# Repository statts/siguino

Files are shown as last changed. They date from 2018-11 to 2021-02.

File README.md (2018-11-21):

# Siguino

Siguino final design

Low power board based on Arduino Pro Mini with in-built Sigfox network support

Siguino Eagle schematics, libraries and Arduino code created by Scott Tattersall

Further project info and manufactured boards for purchase at https://siguino.com

Detailed Getting Started Guide: https://siguino.com/step-by-step-guide/

3rd Party libraries / resources used:

Hardware:
- Many basic components (resistors, capacitors, etc) are from the SparkFun Eagle libraries
- LIS3DH accelerometer from SparkFun: https://github.com/sparkfun/SparkFun_LIS3DH_Arduino_Library
- Wisol Chip from hellogitty/WiSol (greatech.de) https://github.com/hellogitty/WiSOL

Software:
 (To install, go to url and "download zip", in Arduino IDE click Sketch->Include Library->Add zip and select downloaded zip file)
- LowPower library from RocketScream: https://github.com/rocketscream/Low-Power
- SparkFun LIS3DH library (https://github.com/sparkfun/SparkFun_LIS3DH_Arduino_Library)
- Arduino Sensors library (https://github.com/adafruit/Adafruit_Sensor)
- Arduino Bosch BME280 library (https://github.com/adafruit/Adafruit_BME280_Library)
- AltSoftSerial (https://github.com/PaulStoffregen/AltSoftSerial)

Enclosure:
- CAD (STL) files for sample enclosure that can be 3d printed as needed
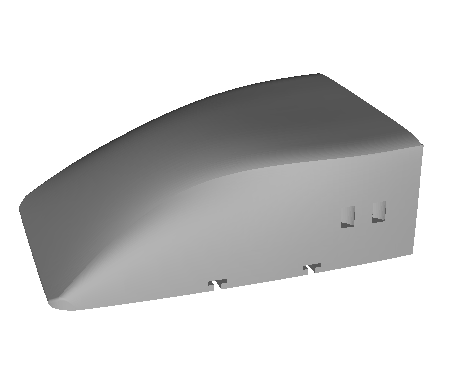
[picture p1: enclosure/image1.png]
Siguino enclosure side view

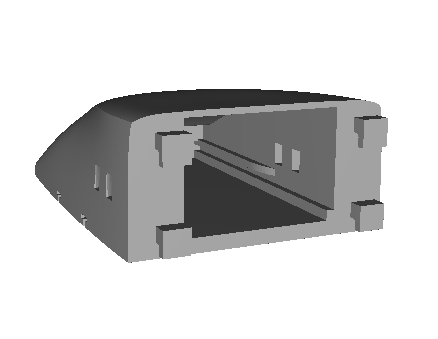
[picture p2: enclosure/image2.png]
Siguino enclosure inside


# Sample projects
Along with the sigfox_sensors project that sends all sensor information here is another simple example project:

- Weather Station (arduino/weather_station)
Follow the same above software section to install the approriate libraries first, then download the weather station code.
The code can be flashed onto the Siguino via a standard FTDI breakout board (3.3v version only!), e.g. 
https://www.sparkfun.com/products/9873

The code: A simple weather station that sends avg temperature, light level, humidity and atmospheric pressure. If using Wia to process the data (see above getting started link), these can be easily graphed in Wia using a Wia Widget:
https://developers.wia.io/docs/add-a-widget

More information on integrating with Wia:
https://siguino.com/getting-started-with-siguino-and-wia-io/

Example:

Sample Temperature Chart (Wia)

# Eagle libraries
In eagle, set the directories for libraries to add the libary files included here if not already included, e.g.
$EAGLEDIR/lbr:{PROJECT-DIR}/Libraries/SparkFun-Eagle-Libraries-master:{PROJECT-DIR}/Libraries/WiSOL-master/Eagle_Library

Plus use the New Library -> execute script to add the components in script form from the scripts dir

# Hardware Revision History:

Rev 0.1: First version, trimmed board

Rev 0.2:
1) Add Reset Pin out as well as dtr for bootloading
2) Change C8 10uf format to standard 0603
3) Update routing to account for unsaved work
4) Re-write/tidy arduino sketch
5) Add de-coupling caps 10uf, 100nf to Accel chip VDD
6) Connect INT1 pin on Accel to D3

Rev 0.3:
1) Add Battery Holder
2) Add Reverse polarity Protection
3) Reposition Antenna

Rev 0.4:
1) Replace Temperature chip
2) Re-route temperature chip
3) Add registration hole for battery holder
4) Minor re-routing of vias under chips

Rev 0.5 / 1.0:
1) Added Magnetometer
2) Replaced temp chip with Temp & Pressure (Bosch BME 280)
3) Re-routing for manufacturing

Rev 1.1:
1) Improved Schematic (with thanks to Marnix Janse)
2) Improved Antenna trace (with thanks to Marnix Janse)

# Licence & Contact

Siguino Hardware and Software licenced under GPLv3, any questions or issues please contact scott@dock.ie

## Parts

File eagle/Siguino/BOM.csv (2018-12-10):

Part | Value | Device | Package | Description | DESCRIPTION | DIGI-KEY_PART_NUMBER | DIGI-KEY_PURCHASE_URL | MF | MP | PACKAGE | PROD_ID | SF_ID | VALUE
ANT1 | PROOB471 | PROANT_PRO-OB-471_ONBOARD | PROANT_ONBOARD_SMD_868_915 | Proant OnBoard Antenna PRO-OB-471 for 868/915MHz comms (e.g. SigFox)
BATT1 | SPARKFUN-BATTERIES_CR2-BATTERY-HOLDERPTH | SPARKFUN-BATTERIES_CR2-BATTERY-HOLDERPTH | SPARKFUN-BATTERIES_BATTERYHOLDER-CR2 | CR2 Battery holder from MPD, see DigiKey product here:
C1 | 0.1uF | 0.1UF-0603-25V-5% | 0603 | 0.1µF ceramic capacitors |  |  |  |  |  |  | CAP-08604 |  | 0.1uF
C2 | 0.1uF | 0.1UF-0603-25V-5% | 0603 | 0.1µF ceramic capacitors |  |  |  |  |  |  | CAP-08604 |  | 0.1uF
C3 | 0.1uF | 0.1UF-0603-25V-5% | 0603 | 0.1µF ceramic capacitors |  |  |  |  |  |  | CAP-08604 |  | 0.1uF
C4 | 0.6pF | 0.8PF-0402-50V-0.1PF | 0402 | 0.8pF ceramic capacitors |  |  |  |  |  |  | CAP-13456 |  | 0.8pF
C5 | 2.2pF | 0.8PF-0402-50V-0.1PF | 0402 | 0.8pF ceramic capacitors |  |  |  |  |  |  | CAP-13456 |  | 0.8pF
C6 | 0.7pF | 0.8PF-0402-50V-0.1PF | 0402 | 0.8pF ceramic capacitors |  |  |  |  |  |  | CAP-13456 |  | 0.8pF
C7 | 0 OHM | RESISTOR0402 | 0402 | Generic Resistor Package
C8 | 100nF | 0.1UF-0603-25V-5% | 0603 | 0.1µF ceramic capacitors |  |  |  |  |  |  | CAP-08604 |  | 0.1uF
C9 | 10nF | 10NF-0603-50V-10% | 0603 | 0.01uF/10nF/10,000pF ceramic capacitors |  |  |  |  |  |  | CAP-00867 |  | 10nF
C10 | 0.1uF | 0.1UF-0603-25V-(+80/-20%) | 0603 | 0.1µF ceramic capacitors |  |  |  |  |  |  | CAP-00810 |  | 0.1uF
C11 | 0.1uF | 0.1UF-0603-25V-5% | 0603 | 0.1µF ceramic capacitors |  |  |  |  |  |  | CAP-08604 |  | 0.1uF
C12 | 100pF | 100PF-0603-50V-5% | 0603 | 100pF/0.1nF ceramic capacitors |  |  |  |  |  |  | CAP-07883 |  | 100pF
C13 | 0.1uF | 0.1UF-0603-25V-(+80/-20%) | 0603 | 0.1µF ceramic capacitors |  |  |  |  |  |  | CAP-00810 |  | 0.1uF
C15 | 10uF | 10UF-0603-6.3V-20% | 0603 | 10.0µF ceramic capacitors |  |  |  |  |  |  | CAP-11015 |  | 10uF
D1 | RED | LED-RED0603 | LED-0603 | Red SMD LED |  |  |  |  |  |  | DIO-00819 |  | RED
HALL1 | TR-J_AH9246-W7 | TR-J_AH9246-W7 | TR-J_SC-59 | Hall effect switch, surface mount, part number AH9246-W-7
J1 | FTDI Basic | 6_PIN_SERIAL_TARGET | 1X06 | 6-pin header connection for use with the FTDI BASIC" pinout - TARGET SIDE."
J2 |  | CONN_12 | 1X12 | Multi connection point. Often used as Generic Header-pin footprint for 0.1 inch spaced/style header connections
J3 |  | CONN_03 | 1X03 | Multi connection point. Often used as Generic Header-pin footprint for 0.1 inch spaced/style header connections
Q1 | MOSFET P-CH 20V 5.3A SOT-23 | MOSFET_PCHSI2323DDS | SOT23-3 | P-channel MOSFETs |  |  |  |  |  |  | SI2323DDS-T1-GE3 |  | MOSFET P-CH 20V 5.3A SOT-23
R1 | 330 | 330OHM-0603-1/10W-1% | 0603 | 330Ω resistor |  |  |  |  |  |  | RES-00818 |  | 330
R2 | PHOTOCELLPTH | PHOTOCELLPTH | PHOTOCELL | Photocell (Photodetector, Photo Resistor, CdS) |  |  |  |  |  |  | COMP-09129 | SEN-09088
R3 | 1k | 1KOHM-0603-1/10W-1% | 0603 | 1kΩ resistor |  |  |  |  |  |  | RES-07856 |  | 1k
R4 | 10k | 10KOHM-0603-1/10W-1% | 0603 | 10kΩ resistor |  |  |  |  |  |  | RES-00824 |  | 10k
R5 | 100k | 100KOHM-0603-1/10W-1% | 0603 | 100kΩ resistor |  |  |  |  |  |  | RES-07828 |  | 100k
R6 | 10k | 10KOHM-0603-1/10W-1% | 0603 | 10kΩ resistor |  |  |  |  |  |  | RES-00824 |  | 10k
R7 | 10k | 10KOHM-0603-1/10W-1% | 0603 | 10kΩ resistor |  |  |  |  |  |  | RES-00824 |  | 10k
SFM1 |  | WISOL_WSSFM10HANDSOLDER | WISOL_WSSFM10 | WiSOL WSSFM10 Sigfox Module with PCB Footprint to enable handsolder
U1 | ATMEGA328P_TQFP | ATMEGA328P_TQFP | TQFP32-08 | Popular 328P in QFP |  |  |  |  |  |  | IC-09069 |  | ATMEGA328P_TQFP
U2 | LIS3MDLTR_LIS3MDLTR | LIS3MDLTR_LIS3MDLTR | LIS3MDLTR_LGA12R50P4X4_200X200X100 | LIS3MDL Series 3 Axis ±2/±8/±12/±16 g 3.6V High Performance Magnetometer LGA-12 | SENSOR MAGMTR I2C/SPI 12LGA | 497-13892-1-ND | https://www.digikey.co.uk/product-detail/en/stmicroelectronics/LIS3MDLTR/497-13892-1-ND/4309737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 | STMicroelectronics | LIS3MDLTR | VFLGA-12 STMicroelectronics
U3 | SPARKFUN-SENSORS_LIS3DH | SPARKFUN-SENSORS_LIS3DH | SPARKFUN-SENSORS_LGA-16-3X3 | ST Microelectronics LIS3DH 3-Axis +/-2/4/8/16g SPI/I2C Accelerometer |  |  |  |  |  |  | IC-13419 | N/A
U4 | BME280 | BME280COMPONENTLIBRARY_BME280 | BME280COMPONENTLIBRARY_BME280_LGA |  |  |  |  |  |  |  | IC-13090 |  | BME280
Y1 | 8MHz | RESONATOR-8MHZSMD_3.2X1.3 | RESONATOR-SMD-3.2X1.3 | 8MHz Resonator |  |  |  |  |  |  | XTAL-08895 |  | 8MHz

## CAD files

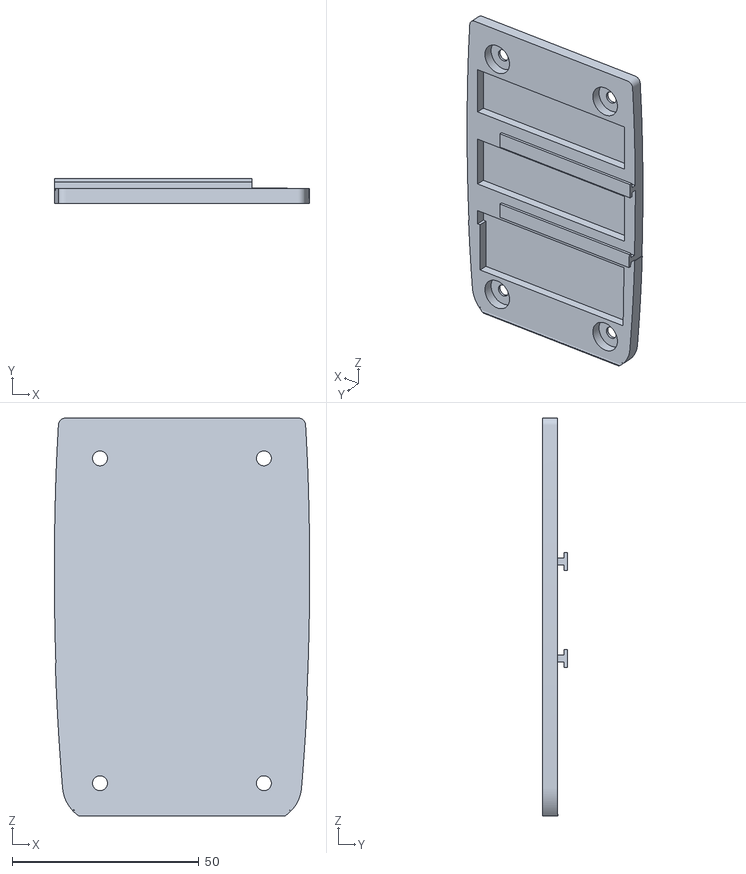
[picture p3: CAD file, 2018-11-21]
enclosure/MOUNTING PLATE.STL
68.5 x 6.71 x 106.7

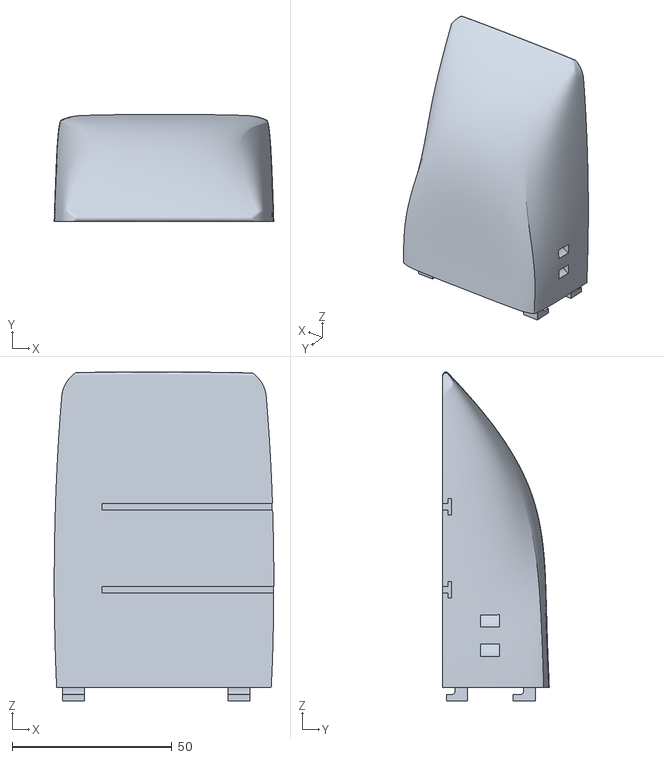
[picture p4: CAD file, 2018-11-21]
enclosure/ENCLOSURE.STL
68.8 x 33.4 x 103.0

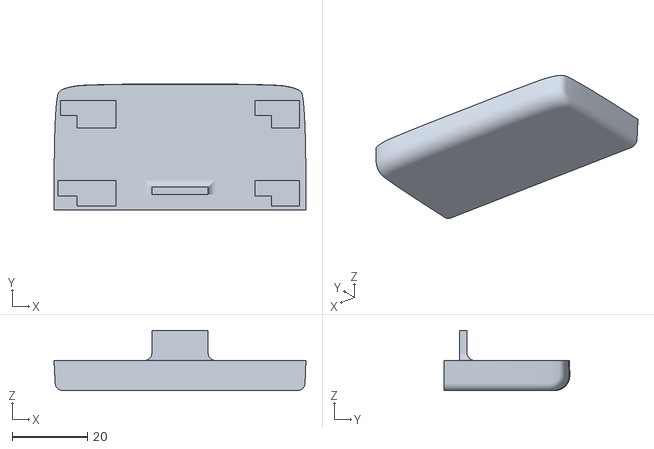
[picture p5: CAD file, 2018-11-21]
enclosure/BATTERY CAP.STL
67.2 x 33.5 x 16.0

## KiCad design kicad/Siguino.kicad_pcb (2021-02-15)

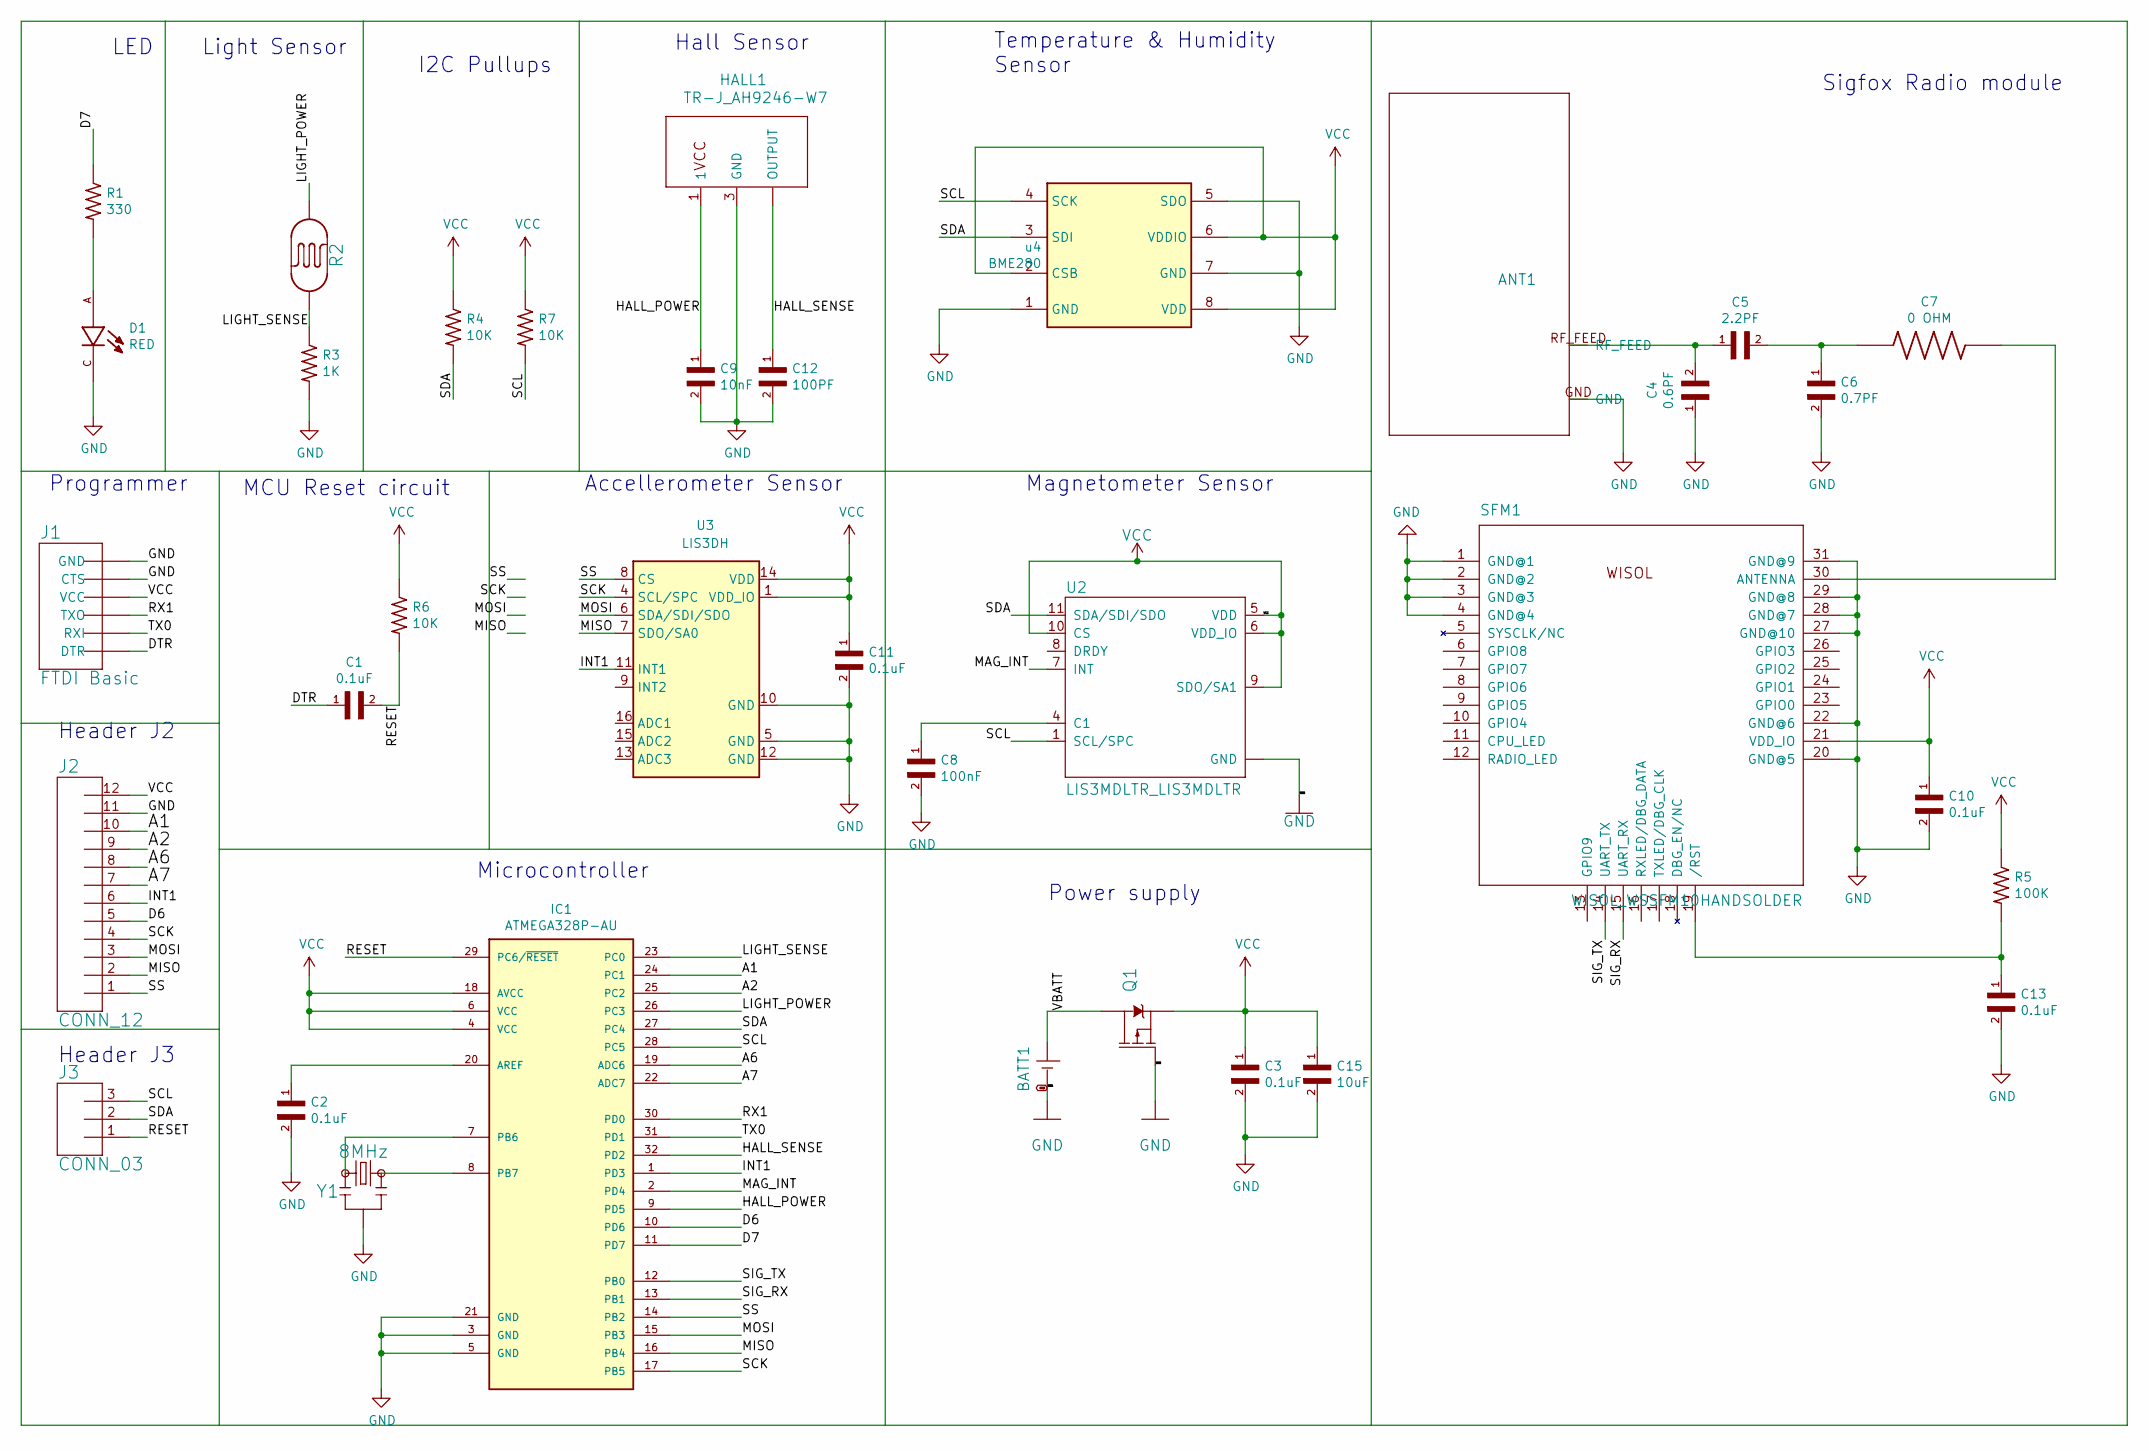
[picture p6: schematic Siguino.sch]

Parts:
ANT1: PROOB471; ONBOARD_SMD_2400
BATT1: SPARKFUN-BATTERIES_CR2-BATTERY-HOLDERPTH; SPARKFUN-BATTERIES_BATTERYHOLDER-CR2
C1, C2, C3, C10, C11, C13: 0.1uF; CAPC0603X33N
C4: 0.6PF; CAPC0402X22N
C5: 2.2PF; CAPC0402X22N
C6: 0.7PF; CAPC0402X22N
C7: 0 OHM; RESC1005X35N
C8: 100nF; CAPC0603X33N
C9: 10nF; CAPC0603X33N
C12: 100PF; CAPC0603X33N
C15: 10uF; CAPC0603X33N
D1: RED; LED_SML-D12Y1WT86
HALL1: TR-J_AH9246-W7; SC-59
IC1: ATMEGA328P-AU; QFP80P900X900X120-32N
J1: FTDI Basic; 1X06
J2: CONN_12; 1X12
J3: CONN_03; 1X03
Q1: MOSFET P-CH 20V 5.3A SOT-23; SOT23-3
R1: 330; RESC1608X50N; Tolerance .1%; Voltage_Rating 50 V
R2: PHOTOCELLPTH; PHOTOCELL
R3: 1K; RESC1608X50N; Tolerance .1%; Voltage_Rating 50 V
R4, R6, R7: 10K; RESC1608X50N; Tolerance .1%; Voltage_Rating 50 V
R5: 100K; RESC1608X50N; Tolerance .1%; Voltage_Rating 50 V
SFM1: WISOL_WSSFM10HANDSOLDER; WISOL_WSSFM10
U2: LIS3MDLTR_LIS3MDLTR; LIS3MDLTR_LGA12R50P4X4_200X200X100
U3: LIS3DH; LGA-16_3x3mm_P0.5mm_LayoutBorder3x5y
Y1: 8MHz; RESONATOR-SMD-3.2X1.3
u4: BME280; Bosch_LGA-8_2.5x2.5mm_P0.65mm_ClockwisePinNumbering

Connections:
/A1: IC1.24 (PC1), J2.10
/A2: IC1.25 (PC2), J2.9
/A6: IC1.19 (ADC6), J2.8
/A7: IC1.22 (ADC7), J2.7
/D6: IC1.10 (PD6), J2.5
/D7: IC1.11 (PD7), R1.1
/DTR: C1.1, J1.1 (DTR)
/HALL_POWER: C9.1, HALL1.1, IC1.9 (PD5)
/HALL_SENSE: C12.1, HALL1.2 (OUTPUT), IC1.32 (PD2)
/INT1: IC1.1 (PD3), J2.6, U3.11 (INT1)
/LIGHT_POWER: IC1.26 (PC3), R2.1
/LIGHT_SENSE: IC1.23 (PC0), R2.2, R3.1
/MAG_INT: IC1.2 (PD4), U2.7 (INT)
/MISO: IC1.16 (PB4), J2.2, U3.7 (SDO/SA0)
/MOSI: IC1.15 (PB3), J2.3, U3.6 (SDA/SDI/SDO)
/RESET: C1.2, IC1.29 (PC6/~RESET), J3.1, R6.2
/RX1: IC1.30 (PD0), J1.3 (TXO)
/SCK: IC1.17 (PB5), J2.4, U3.4 (SCL/SPC)
/SCL: IC1.28 (PC5), J3.3, R7.2, U2.1 (SCL/SPC), u4.4 (SCK)
/SDA: IC1.27 (PC4), J3.2, R4.2, U2.11 (SDA/SDI/SDO), u4.3 (SDI)
/SIG_RX: IC1.13 (PB1), SFM1.15 (UART_RX)
/SIG_TX: IC1.12 (PB0), SFM1.14 (UART_TX)
/SS: IC1.14 (PB2), J2.1, U3.8 (CS)
/TX0: IC1.31 (PD1), J1.2 (RXI)
/VBATT: BATT1.VBATT, Q1.3 (D)
GND: ANT1.GND, BATT1.GND, C2.2, C3.2, C4.1, C6.2, C8.2, C9.2, C10.2, C11.2, C12.2, C13.2, C15.2, D1.C, HALL1.3 (GND), IC1.3 (GND), IC1.5 (GND), IC1.21 (GND), J1.5 (CTS), J1.6 (GND), J2.11, Q1.1 (G), R3.2, SFM1.1 (GND@1), SFM1.2 (GND@2), SFM1.3 (GND@3), SFM1.4 (GND@4), SFM1.20 (GND@5), SFM1.22 (GND@6), SFM1.27 (GND@10), SFM1.28 (GND@7), SFM1.29 (GND@8), SFM1.31 (GND@9), U2.2 (GND), U2.3 (GND), U2.12 (GND), U3.5 (GND), U3.10 (GND), U3.12 (GND), Y1.2, u4.1 (GND), u4.5 (SDO), u4.7 (GND)
unnamed: ANT1.RF_FEED, C4.2, C5.1
unnamed: C2.1, IC1.20 (AREF)
unnamed: C5.2, C6.1, C7.1
unnamed: C7.2, SFM1.30 (ANTENNA)
unnamed: C8.1, U2.4 (C1)
unnamed: C13.1, R5.2, SFM1.19 (/RST)
unnamed: D1.A, R1.2
unnamed: IC1.7 (PB6), Y1.1
unnamed: IC1.8 (PB7), Y1.3
VCC: C3.1, C10.1, C11.1, C15.1, IC1.4 (VCC), IC1.6 (VCC), IC1.18 (AVCC), J1.4 (VCC), J2.12, Q1.2 (S), R4.1, R5.1, R6.1, R7.1, SFM1.21 (VDD_IO), U2.5 (VDD), U2.6 (VDD_IO), U2.9 (SDO/SA1), U2.10 (CS), U3.1 (VDD_IO), U3.14 (VDD), u4.2 (CSB), u4.6 (VDDIO), u4.8 (VDD)

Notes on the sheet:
Light Sensor
I2C Pullups
Hall Sensor
Temperature & Humidity Sensor
Magnetometer Sensor
Accellerometer Sensor
LED
MCU Reset circuit
Programmer
Header J2
Header J3
Microcontroller
Power supply
Sigfox Radio module

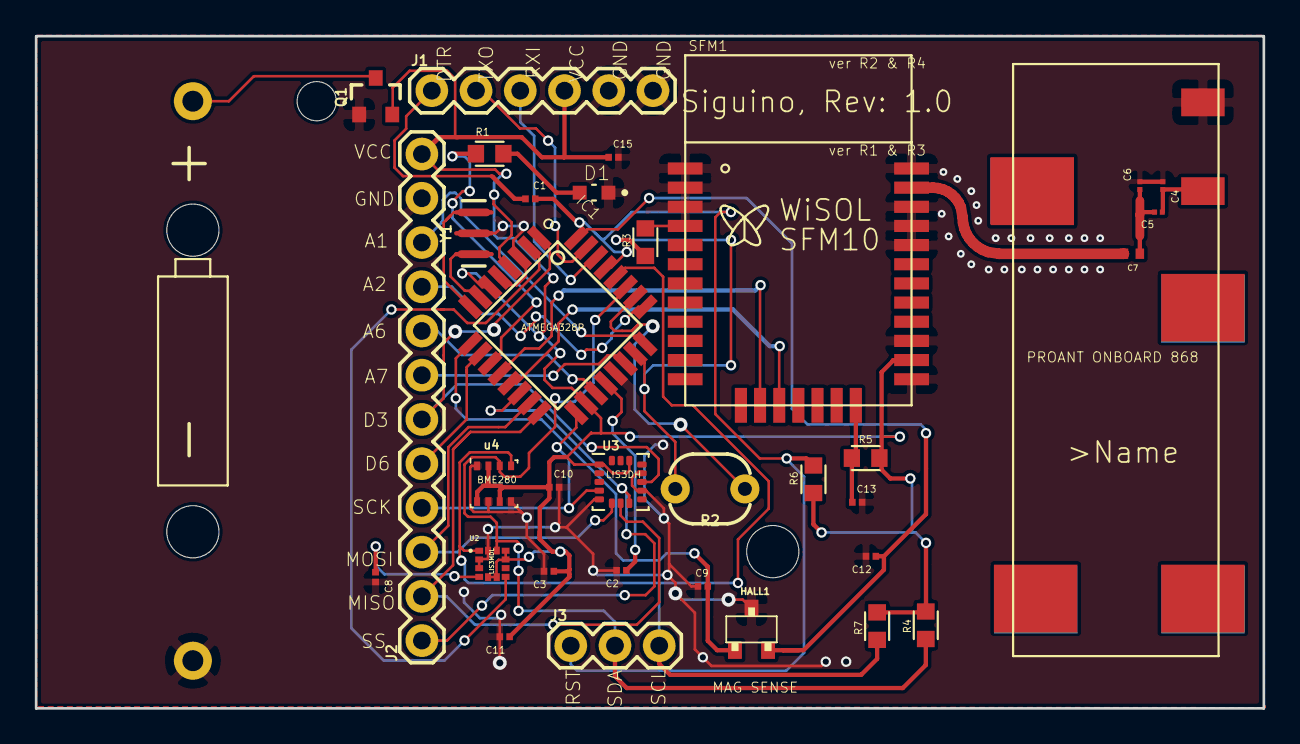
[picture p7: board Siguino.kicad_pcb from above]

Board: 16 copper layers, 70.5 x 38.6 mm, 36 parts (0 on the bottom side), 36 nets.

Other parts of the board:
@HOLE0: (no value)

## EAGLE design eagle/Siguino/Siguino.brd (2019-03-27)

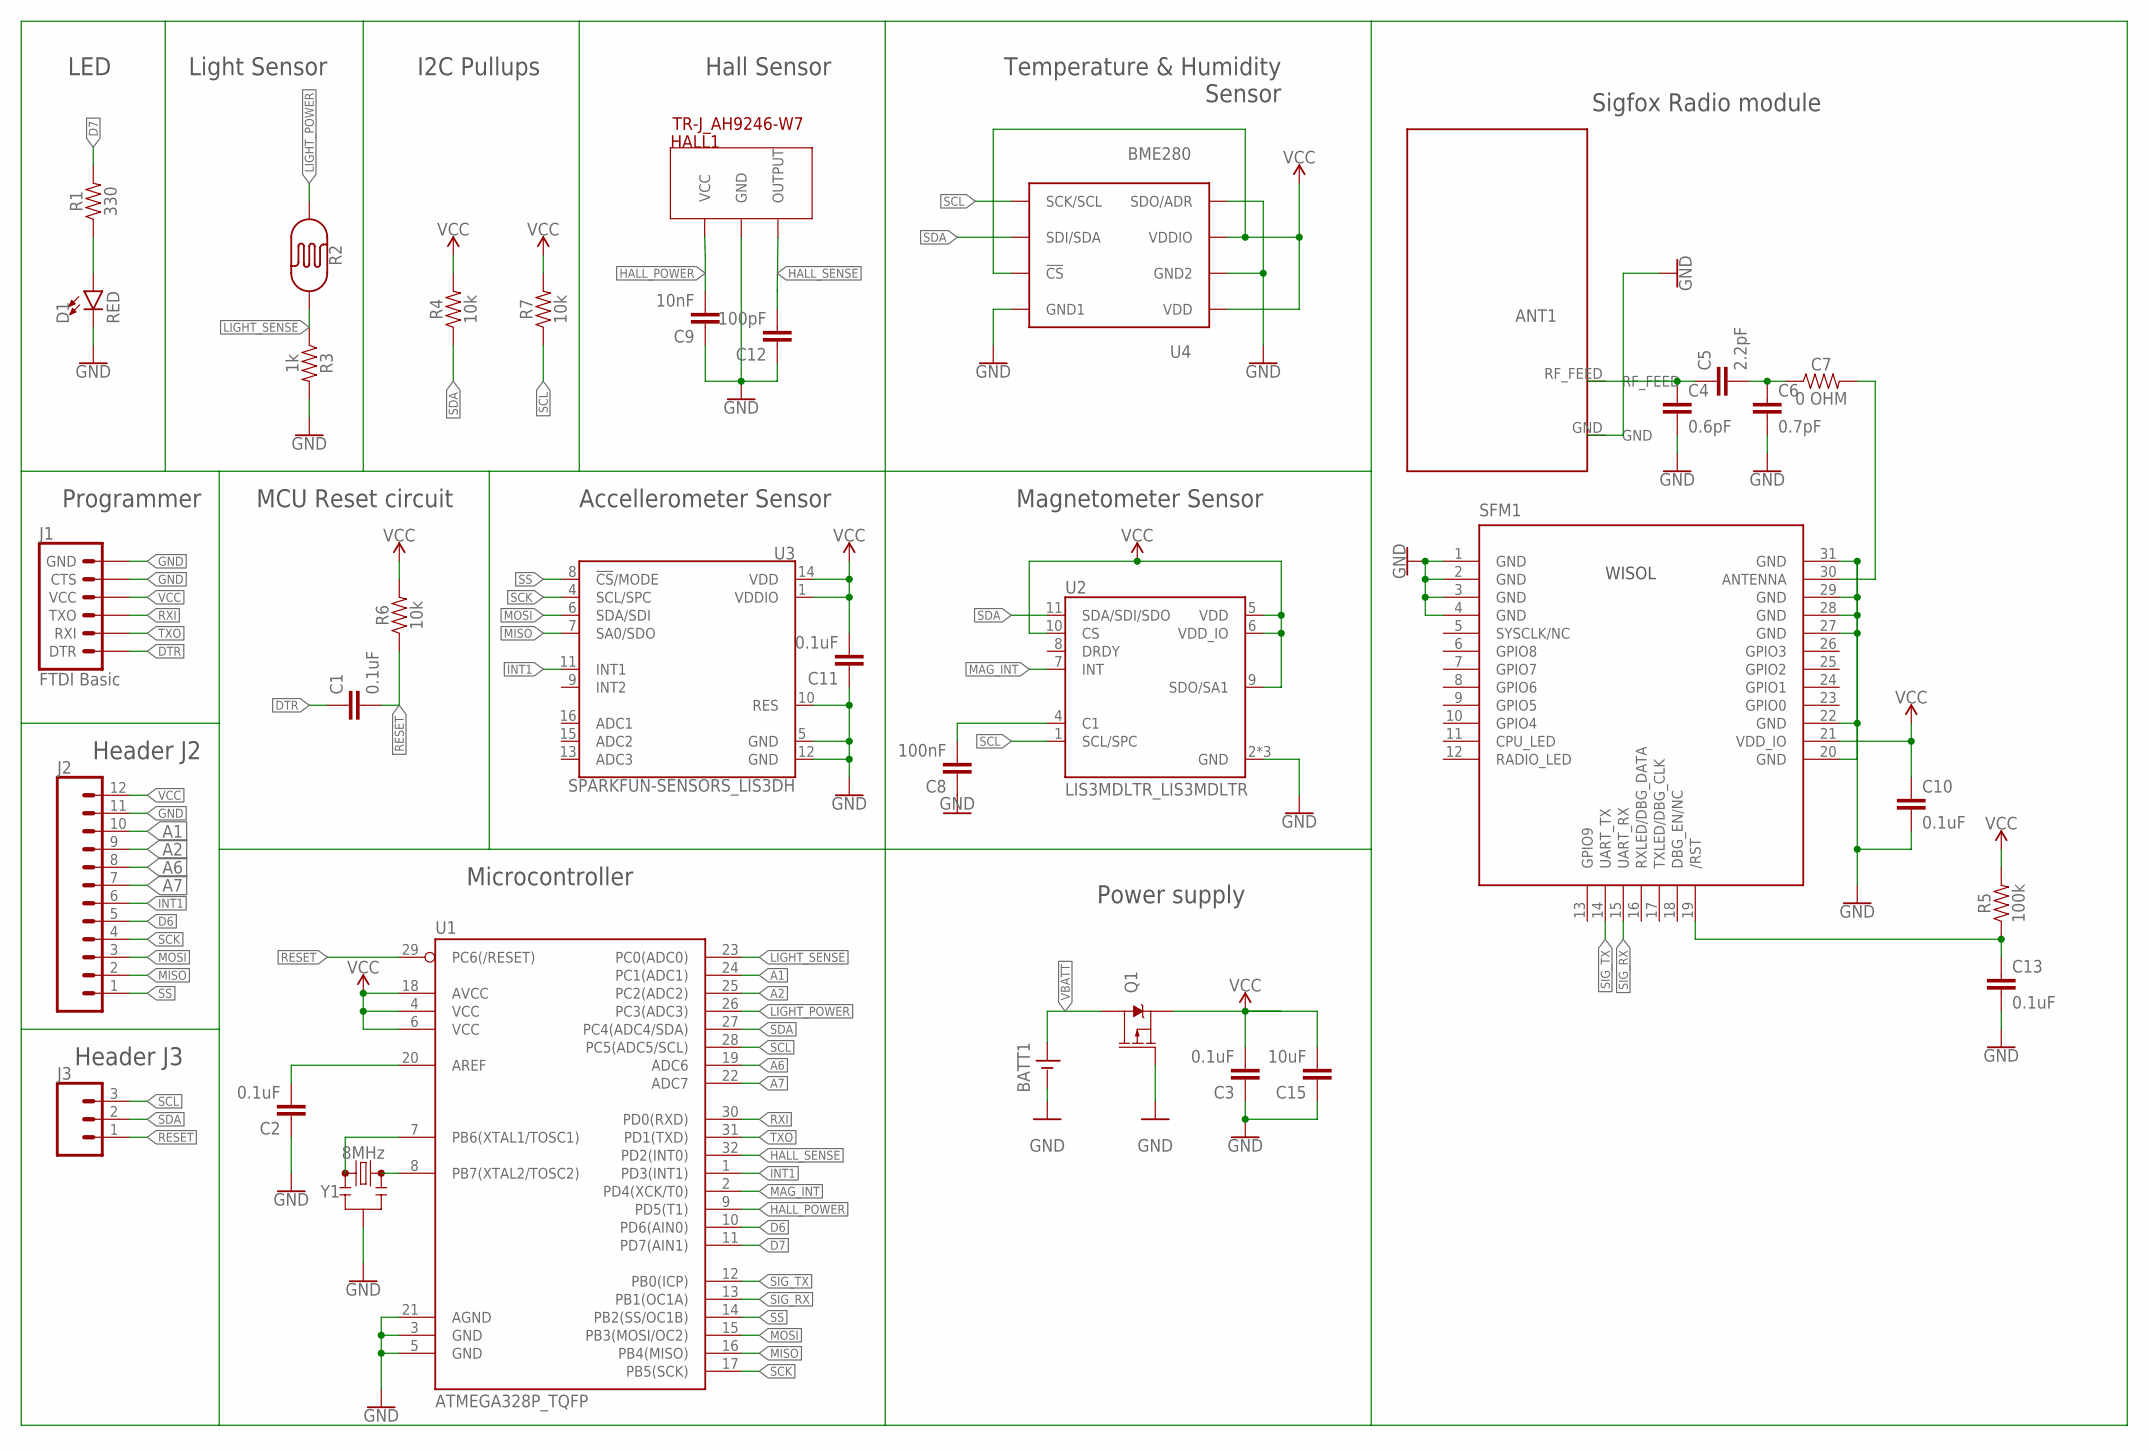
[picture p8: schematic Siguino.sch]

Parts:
ANT1: PROOB471; ONBOARD_SMD_2400
BATT1: SPARKFUN-BATTERIES_CR2-BATTERY-HOLDERPTH; SPARKFUN-BATTERIES_BATTERYHOLDER-CR2
C1, C2, C3, C10, C11, C13: 0.1uF; 0603
C4: 0.6pF; 0402
C5: 2.2pF; 0402
C6: 0.7pF; 0402
C7: 0 OHM; 0402
C8: 100nF; 0603
C9: 10nF; 0603
C12: 100pF; 0603
C15: 10uF; 0603
D1: RED; LED-0603
HALL1: TR-J_AH9246-W7; TR-J_SC-59
J1: FTDI Basic; 1X06
J2: CONN_12; 1X12
J3: CONN_03; 1X03
Q1: MOSFET P-CH 20V 5.3A SOT-23; SOT23-3
R1: 330; 0603
R2: PHOTOCELLPTH; PHOTOCELL
R3: 1k; 0603
R4, R6, R7: 10k; 0603
R5: 100k; 0603
SFM1: WISOL_WSSFM10HANDSOLDER; WISOL_WSSFM10
U1: ATMEGA328P_TQFP; TQFP32-08
U2: LIS3MDLTR_LIS3MDLTR; LIS3MDLTR_LGA12R50P4X4_200X200X100
U3: SPARKFUN-SENSORS_LIS3DH; SPARKFUN-SENSORS_LGA-16-3X3
U4: BME280; BME280COMPONENTLIBRARY_BME280_LGA
Y1: 8MHz; RESONATOR-SMD-3.2X1.3

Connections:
A1: J2.10, U1.24 (PC1(ADC1))
A2: J2.9, U1.25 (PC2(ADC2))
A6: J2.8, U1.19 (ADC6)
A7: J2.7, U1.22 (ADC7)
D6: J2.5, U1.10 (PD6(AIN0))
D7: R1.2, U1.11 (PD7(AIN1))
DTR: C1.1, J1.1 (DTR)
GND: ANT1.GND, BATT1.GND, C2.1, C3.1, C4.2, C6.2, C8.1, C9.1, C10.2, C11.1, C12.1, C13.2, C15.1, D1.C, HALL1.3 (GND), J1.5 (CTS), J1.6 (GND), J2.11, Q1.1 (G), R3.2, SFM1.1 (GND), SFM1.2 (GND), SFM1.3 (GND), SFM1.4 (GND), SFM1.20 (GND), SFM1.22 (GND), SFM1.27 (GND), SFM1.28 (GND), SFM1.29 (GND), SFM1.31 (GND), U1.3 (GND), U1.5 (GND), U1.21 (AGND), U2.2 (GND), U2.3 (GND), U2.12 (GND), U3.5 (GND), U3.10 (RES), U3.12 (GND), U4.P$1 (GND1), U4.P$5 (SDO/ADR), U4.P$7 (GND2), Y1.2
HALL_POWER: C9.2, HALL1.1 (VCC), U1.9 (PD5(T1))
HALL_SENSE: C12.2, HALL1.2 (OUTPUT), U1.32 (PD2(INT0))
INT1: J2.6, U1.1 (PD3(INT1)), U3.11 (INT1)
LIGHT_POWER: R2.1, U1.26 (PC3(ADC3))
LIGHT_SENSE: R2.2, R3.1, U1.23 (PC0(ADC0))
MAG_INT: U1.2 (PD4(XCK/T0)), U2.7 (INT)
MISO: J2.2, U1.16 (PB4(MISO)), U3.7 (SA0/SDO)
MOSI: J2.3, U1.15 (PB3(MOSI/OC2)), U3.6 (SDA/SDI)
unnamed: C2.2, U1.20 (AREF)
unnamed: U1.8 (PB7(XTAL2/TOSC2)), Y1.3
unnamed: U1.7 (PB6(XTAL1/TOSC1)), Y1.1
unnamed: ANT1.RF_FEED, C4.1, C5.1
unnamed: C13.1, R5.1, SFM1.19 (/RST)
unnamed: C7.2, SFM1.30 (ANTENNA)
unnamed: C5.2, C6.1, C7.1
unnamed: C8.2, U2.4 (C1)
unnamed: D1.A, R1.1
RESET: C1.2, J3.1, R6.1, U1.29 (PC6(/RESET))
RXI: J1.3 (TXO), U1.30 (PD0(RXD))
SCK: J2.4, U1.17 (PB5(SCK)), U3.4 (SCL/SPC)
SCL: J3.3, R7.1, U1.28 (PC5(ADC5/SCL)), U2.1 (SCL/SPC), U4.P$4 (SCK/SCL)
SDA: J3.2, R4.1, U1.27 (PC4(ADC4/SDA)), U2.11 (SDA/SDI/SDO), U4.P$3 (SDI/SDA)
SIG_RX: SFM1.15 (UART_RX), U1.13 (PB1(OC1A))
SIG_TX: SFM1.14 (UART_TX), U1.12 (PB0(ICP))
SS: J2.1, U1.14 (PB2(SS/OC1B)), U3.8 (!CS!/MODE)
TXO: J1.2 (RXI), U1.31 (PD1(TXD))
VBATT: BATT1.VBATT, Q1.3 (D)
VCC: C3.2, C10.1, C11.2, C15.2, J1.4 (VCC), J2.12, Q1.2 (S), R4.2, R5.2, R6.2, R7.2, SFM1.21 (VDD_IO), U1.4 (VCC), U1.6 (VCC), U1.18 (AVCC), U2.5 (VDD), U2.6 (VDD_IO), U2.9 (SDO/SA1), U2.10 (CS), U3.1 (VDDIO), U3.14 (VDD), U4.P$2 (!CS), U4.P$6 (VDDIO), U4.P$8 (VDD)

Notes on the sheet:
Light Sensor
I2C Pullups
Hall Sensor
Temperature & Humidity Sensor
Magnetometer Sensor
Accellerometer Sensor
LED
MCU Reset circuit
Programmer
Header J2
Header J3
Microcontroller
Power supply
Sigfox Radio module

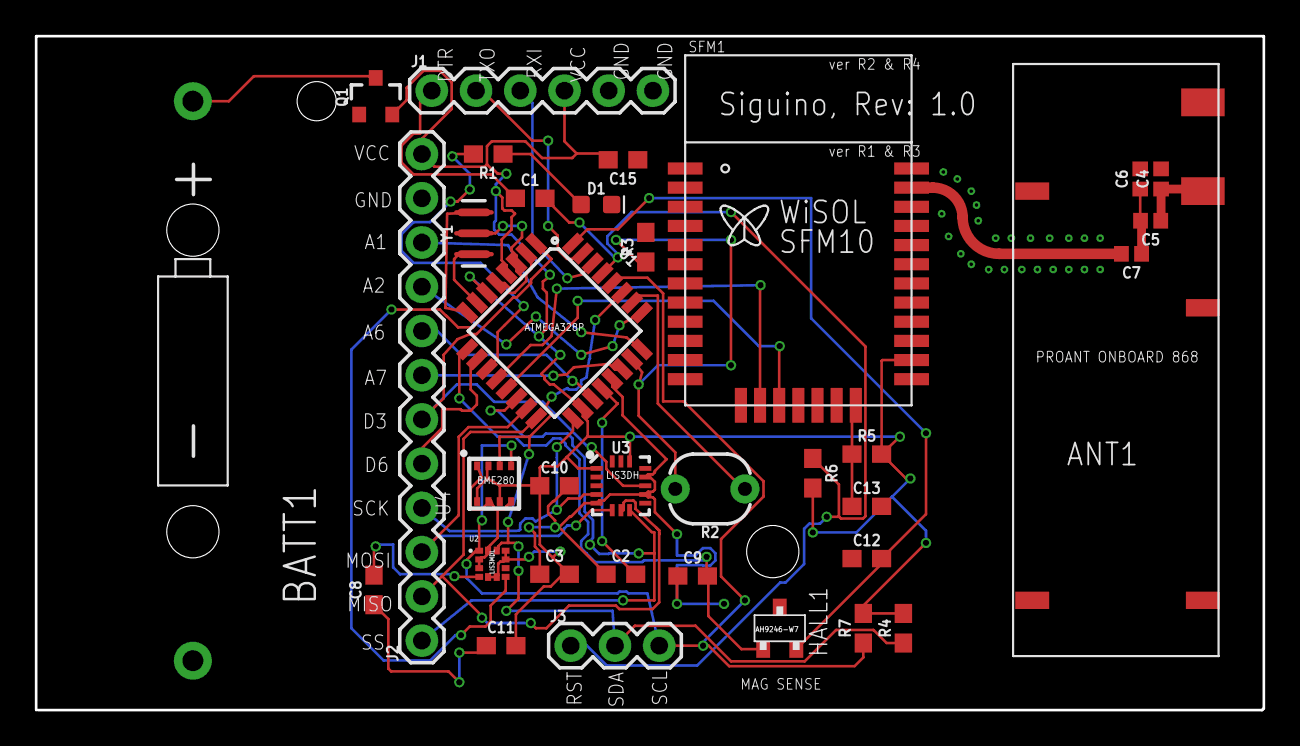
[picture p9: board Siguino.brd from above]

Board: 2 copper layers, 70.5 x 38.7 mm, 35 parts (0 on the bottom side), 36 nets.

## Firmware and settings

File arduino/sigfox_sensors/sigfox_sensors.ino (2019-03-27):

//third-party libraries (install per normal Arduino instructions: https://www.arduino.cc/en/hacking/libraries
#include <LowPower.h> //from RocketScream: https://github.com/rocketscream/Low-Power
#include <SparkFunLIS3DH.h> // from SparkFun: https://github.com/sparkfun/SparkFun_LIS3DH_Arduino_Library
#include <Adafruit_BME280.h>

#include "BitPacker.h"
#include "util.h"
#include "Sigfox.h"
#include "accel.h"
#include "magnet.h"

#define SEALEVELPRESSURE_HPA (1013.25)

Adafruit_BME280 bme; // I2C
//Adafruit_BMP280 bmp(BMP_CS); // hardware SPI
//Adafruit_BMP280 bmp(BMP_CS, BMP_MOSI, BMP_MISO,  BMP_SCK);

const byte BME_ADDRESS   =  0x76;

//set to false for debug and to avoid sending messages but still take sensor readings
bool SEND_SIGFOX_MESSAGES = true;

//declare LIS3DH accelerometer
LIS3DH myIMU(SPI_MODE, 10); // constructed with parameters for SPI and cs pin number

//"global" vars
int period_count = SIGFOX_WAIT_PERIODS; //start at max so initial message is sent on startup
int num_readings = 0;
volatile byte shock_state = LOW;
volatile int count = 0;
volatile bool interrupt_listen_shock = true;
bool shock_powered_down = false;
volatile byte mag_state = HIGH;
volatile bool interrupt_listen_mag = true;
volatile bool state_changed_mag = false;
bool mag_opened = false;
unsigned int seq_num = 0;
enum POWER_MODE {OFF = 0, ON = 1};
int init_vcc = 0;
  int total_light = 0;
  float total_temp = 0;
  float total_pressure = 0;
  float total_humidity = 0;
  float total_altitude = 0;

void setup(){
  pinMode(LED_PIN, OUTPUT);
  pinMode(LIGHT_PWR_PIN,OUTPUT);
  pinMode(LIGHT_SENSOR_PIN, INPUT); //defaults to INPUT anyway, not strictly necessary
  digitalWrite(LIGHT_PWR_PIN, LOW);  
  Serial.begin(9600);

  pinMode(INT_PIN_SHOCK, INPUT_PULLUP);
  pinMode(INT_PIN_MAG, INPUT_PULLUP);
  pinMode(MAG_PWR_PIN, OUTPUT);
  set_power_mag(POWER_MODE::ON);

  status_t accel_stat = Accel::setup_accel(&myIMU);
  bool accel_ok = accel_stat == IMU_SUCCESS;

  //attach interrupts so chip wakes if mag pulse or device move occurs
  attachInterrupt(digitalPinToInterrupt(INT_PIN_MAG), interrupt_mag, CHANGE);  
  attachInterrupt(digitalPinToInterrupt(INT_PIN_SHOCK), interrupt_shock, CHANGE);
  delay(300);//Let system settle

  //blink led to show power on
  //Util::blink_led(2);
  
  //sigfox comms test for debug purposes
  bool sigfox_ok = SigFox::test_sigfox_chip();
  
  init_vcc = Util::readVcc();  
  Util::debug_print("Vcc = ", init_vcc, true);
  
  Util::debug_print(F("Set sigfox sleep mode..."));
  SigFox::set_sigfox_sleep(true);
  //need to reset "volatile" variables here to avoid odd results
  shock_state = LOW;
  count = 0;
  mag_state = digitalRead(INT_PIN_MAG);
  state_changed_mag = false;
  interrupt_listen_mag = true;
  
  // setup BME280 chip on appropriate I2C address
  bool bme_status = bme.begin(BME_ADDRESS);  
  if (!bme_status) {
      Serial.println(F("Could not find a valid BME280 sensor, check wiring!"));
  }

  //set up magnetometer
  bool mag_ok = Magnetometer::checkMagnetometer();

  // POST (power on self test) blinks for correct chip operation
  Util::blink_led(1);
  if (sigfox_ok) {
     Util::blink_led(1);
  }else{
     Util::debug_print(F("Sigfox chip not responding correctly"));
     delay(500);   
  }
  if (accel_ok) {
    Util::blink_led(1);
  }else{
     Util::debug_print(F("LIS3DH chip not responding correctly"));
     delay(500);   
  }
  if (mag_ok) {
    Util::blink_led(1);
  }else{
    Util::debug_print(F("Magnetometer not responding correctly"));
     delay(500);   
  }
  if (bme_status) {
    Util::blink_led(1);
  }else{
    Util::debug_print(F("Bosch temp chip not responding correctly"));
     delay(500);   
  }
  
}//end "setup()"

void interrupt_shock() {
  if (interrupt_listen_shock){
    shock_state = !shock_state;
    interrupt_listen_shock=false;
  }
}

void interrupt_mag() {
  if (interrupt_listen_mag){
    state_changed_mag = true;
    mag_opened = !mag_state;
    mag_state = !mag_state;
    count++;
    interrupt_listen_mag=false;
  }
}

bool check_shock_occurred(){
  bool retval = false;
  if (shock_state==HIGH){
    retval = true;
  }
  shock_state = LOW;
  if (shock_powered_down){
    //re-enable shock component
    Util::debug_print(F("Re-enabling shock sensor..."));
    myIMU.begin();
    delay(500);
    shock_powered_down = false;
  }
  interrupt_listen_shock = true;
  return retval;
}

bool check_mag_occurred(){
  bool retval = false;
  if (state_changed_mag){
    retval = true;
    state_changed_mag = false;
  }
  if (!interrupt_listen_mag){
    Util::debug_print(F("Re-enabling mag sensor..."));
    set_power_mag(POWER_MODE::ON);
    delay(10);
  }
  mag_state = digitalRead(INT_PIN_MAG);
  
  interrupt_listen_mag = true;
  return retval;
}

void set_power_mag(int mode){
  if (mode==POWER_MODE::ON){
    digitalWrite(MAG_PWR_PIN, HIGH);
  }else{
    digitalWrite(MAG_PWR_PIN, LOW);
  }
}

float get_temperature_reading(){  
  float temperature = 0.0000;
  temperature = bme.readTemperature();
  return temperature;
}

int get_light_reading(){
  digitalWrite(LIGHT_PWR_PIN, HIGH);
  int light_value =  analogRead(LIGHT_SENSOR_PIN);
  digitalWrite(LIGHT_PWR_PIN, LOW);
  return light_value;
}

// unsigned int vals[] = {seq_num, rounded_temp, avg_light, shock_occurred, mag_occurred, batt_lvl,rounded_pressure,rounded_hum,rounded_alt};
void print_sensor_data(unsigned int vals[]){
    Serial.print(F("Seq num: "));
    Serial.println(vals[0]);
    Serial.println(F("---Seq--|M|S|--Light--|--Temp-|Batt|Pressure|Humidity|Altitude"));
    String hex_bits = String(vals[0], BIN);
    int len = strlen(hex_bits.c_str());
    for (int i=0;i<8 - len;i++){
      Serial.print(" ");
    }
    Serial.print(String(vals[0],BIN));
    Serial.print(F("|"));
    Serial.print(vals[4]);
    Serial.print(F("|"));
    Serial.print(vals[3]);
    Serial.print(F("|"));
    Serial.print(vals[2]);
    Serial.print(F("|"));
    Serial.print(vals[1]);
    Serial.print(F("|"));
    Serial.print(vals[5]);
    Serial.print(F("|"));
    Serial.print(vals[6]);
    Serial.print(F("|"));
    Serial.print(vals[7]);
    Serial.print(F("|"));
    Serial.println(vals[8]);
    
}

String uint64_to_hexstr(uint64_t int64bits) {
  String hex_chars = "0123456789ABCDEF";
  String hexstr = "";
  int ndx;
  for (int i=0; i<16; i++) {
    ndx = int(int64bits & B1111);
    int64bits = int64bits >> 4;
    hexstr = hex_chars.substring(ndx, ndx+1) + hexstr;
  }
  return hexstr;
}

//main program loop
void loop(){  
 


  float f = 0;
  unsigned int ui = 0;

  //check interrupt state and remove interrupt if already occurred (i.e. switch off component)
  if ((!interrupt_listen_shock) && (!shock_powered_down)){
    //if we're not listening anymore it means a shock has occurred
    // this means we can disable (unpower) the device until the next sending period
    Util::debug_print("Powering down shock sensor...");
    myIMU.writeRegister(LIS3DH_CTRL_REG1, 0x00);
    shock_powered_down = true;
  }

  Util::debug_print("Setting Arduino Low Power Mode...");
  if (DEBUG_MODE){
    delay(100); 
  }
  // go to lowest power for maximum period (8 seconds)
  LowPower.powerDown(SLEEP_8S, ADC_OFF, BOD_OFF); 
  
  if (period_count % SENSOR_READ_PERIOD == 0){
    //SENSOR_READ_PERIOD determines how often to read sensor data
    // get temp
    Util::debug_print("Getting sensor information...");    
    f = get_temperature_reading();
    Util::debug_print("Temp (C): ", (int)f, true);
    total_temp += f;

    // get light level
    int light_reading = get_light_reading();
    Util::debug_print("Light: ", light_reading, true);
    total_light += light_reading;

    //get pressure
    f = bme.readPressure() / 100.0F;
    Util::debug_print("Pressure (hPa): ", (int)f, true);
    total_pressure += f;
    
    //get altitude
    f = bme.readAltitude(SEALEVELPRESSURE_HPA);
    Util::debug_print("Altituide (m): ", (int)f, true);
    total_altitude += f;

    //get humidity
    f = bme.readHumidity();
    Util::debug_print("Humidity (%): ", (int)f, true);
    total_humidity += f;
    
    num_readings++; 
  }
  
  if (period_count>=SIGFOX_WAIT_PERIODS){
    //only send data over sigfox every SIGFOX_WAIT_PERIODS (e.g. 8 = 8x8 seconds, ~ every minute)
    Util::debug_print(F("Sending period has occurred..."));
    Util::debug_print(F("Set sigfox wake up..."));
    unsigned int vals[] = {0,0,0,0,0,0,0,0,0};
    SigFox::set_sigfox_sleep(false);  

    vals[0] = seq_num;
    //float avg_temp = total_temp / num_readings;
    ui = total_light / num_readings;
    Util::debug_print("Avg light level: ", ui, true);
  //  String light_bin = String(ui, BIN);
    vals[2] = ui;
       
    ui = Util::round_float((total_temp / num_readings) *2);
    Util::debug_print("Avg Temp (x2, Rounded): ", ui, true);
  //  String temp_bin = String(ui, BIN);
    vals[1] = ui;
    
    ui = min(Util::round_float(total_pressure / num_readings) - MIN_PRESSURE, MAX_PRESSURE);
    Util::debug_print("total_pressure: ", total_pressure, true);
    Util::debug_print("rounded_pressure: ", ui, true);
    //String pressure_bin = String(ui, BIN);
    vals[6] = ui;
    
    ui = Util::round_float(total_humidity / num_readings);
    Util::debug_print("total_humidity: ", total_humidity, true);
    Util::debug_print("rounded_hum: ", ui, true);
    //String hum_bin = String(ui, BIN);
    vals[7] = ui;
    
    ui = min(Util::round_float((total_altitude / num_readings) / 10) - MIN_ALTITUDE, MAX_ALTITUDE);
    Util::debug_print("rounded_alt: ", ui, true);    
    Util::debug_print("total_altitude: ", total_altitude, true);
    //String alt_bin = String(ui, BIN);
    vals[8] = ui;
    //check if shock interrupt has occurred and re-attach interrupts as necessary

    vals[3] = check_shock_occurred();
    vals[4] = check_mag_occurred();
    
  //  int curr_vcc = Util::readVcc();
   // Util::debug_print("Vcc = ", curr_vcc, true);

    ui = (Util::readVcc() / 100) - MIN_BATT_LVL;
    Util::debug_print("Batt lvl = ", ui, true);
    vals[5] = ui;
    
    //String batt_lvl_bin = String(ui, BIN);
    
    //unsigned int vals[] = {seq_num, rounded_temp, avg_light, check_shock_occurred(), check_mag_occurred(), batt_lvl,rounded_pressure,rounded_hum,rounded_alt};
    unsigned int bits[] = {8,7,10,1,1,4,8,7,9};

    if (DEBUG_MODE){
      print_sensor_data(vals);
    }
    
    uint64_t packed = BitPacker::get_packed_message_64(vals, bits, 9);
    String hex_bits = uint64_to_hexstr(packed);
    
    //String hex_bits = String(packed, HEX);
    //if (strlen(hex_bits.c_str())%2==1){
    //  hex_bits = "0" + hex_bits;
    //}
    String msg_header = "Packed bits (HEX): ";    
    Util::debug_print(msg_header + hex_bits);

    if (SEND_SIGFOX_MESSAGES){
      Util::debug_print(F("Sending temperature over SigFox::.."));
    
      digitalWrite(LED_PIN, HIGH);   // turn the LED on (HIGH is the voltage level)
      
      String chip_response = SigFox::send_at_command("AT$SF=" + hex_bits, 6000);
      Util::debug_print("Reponse from sigfox module: " + chip_response);
  
      digitalWrite(LED_PIN, LOW);    // turn the LED off by making the voltage LOW
      
    }else{
      Util::debug_print(F("Skipping Sigfox message sending..."));
    }
    
    Util::debug_print(F("Set sigfox sleep mode..."));
    SigFox::set_sigfox_sleep(true);
    total_temp = 0;
    total_light = 0;
    total_pressure = 0;
    total_humidity = 0;
    total_altitude = 0;
    num_readings = 0;

    period_count = 0;
    seq_num++;
    seq_num = seq_num % 256;
  }
  period_count++;
  //delay(1000);
}// end loop()
  

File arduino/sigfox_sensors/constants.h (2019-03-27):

#ifndef CONSTANTS_H_INCLUDED
#define CONSTANTS_H_INCLUDED

const bool DEBUG_MODE = true;
const int LIGHT_PWR_PIN = 17;   // select the power pin for the photoresistor
const int MAG_PWR_PIN = 5; // select the power pin for the hall effect switch
const int LIGHT_SENSOR_PIN = A0;
const int LED_PIN = 7; //no on-board LED for low pow reasons
const int TX_PIN = 9;
const int SIGFOX_WAIT_PERIODS = 450; //85periods of 8 seconds approx 1 min, 120 ~ 15 mins, 450 = 1hr
const int SENSOR_READ_PERIOD = 2;// read sensors roughly every x periods, x = 8 ~ 1 minute (64 seconds)
const byte INT_PIN_SHOCK = 3;
const byte INT_PIN_MAG = 2;
const int MIN_BATT_LVL = 20;
const int MIN_PRESSURE   = 920;
const int MAX_PRESSURE   = 1070;

//min and max reportable altitude divided by 10
const int MIN_ALTITUDE   = -10;
const int MAX_ALTITUDE   = 500;

#endif // CONSTANTS_H_INCLUDED

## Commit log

2018-05-29 Updated with latest 0.5 and 1.0 changes
    [Siguino.brd, Siguino.sch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]
2018-07-22 Fixed bug with total counters being re-zeroed in loop
    [sigfox_sensors.ino]
2018-08-30 Updated image for temperature chart in samle project
2018-09-14 Updated with fix for US FCC rules and WISOL SFM10R2 chip
    [constants.h, weather_station.ino]
2018-11-08 Cleaned schematic & changed antenna path on Board
    [Siguino.brd, Siguino.sch]
2018-11-21 Updated board and schematic with ERC and DRC check approvals
    [Siguino.sch]
2018-11-21 Added cad files for 3d printing enclosure
    [BATTERY CAP.STL, ENCLOSURE.STL, MOUNTING PLATE.STL]
2018-11-21 Fixed enclosure images
2018-11-21 Fixed enclosure images sizes
2018-12-10 Updated BOM
    [BOM.csv]
2019-02-28 Fixed bit packing issue up to 64bits
    [constants.h, sigfox_sensors.ino]
2019-03-27 Fixed issue with hatching on antenna pads causing RF issues
    [Siguino.brd, Siguino.sch]
2021-02-13 KiCad Siguino Version
    Updated .gitignore for specific kicad files and added a folder with schematic and pcb converted to KiCad
    [Siguino.kicad_pcb, Siguino.sch]

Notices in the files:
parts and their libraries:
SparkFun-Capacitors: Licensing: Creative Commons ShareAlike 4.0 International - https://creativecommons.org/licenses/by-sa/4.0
